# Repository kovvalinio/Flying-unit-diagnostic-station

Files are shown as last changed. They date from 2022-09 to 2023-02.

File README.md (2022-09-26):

# Flying-unit-diagnostic-station
This is the development repository for the embedded system created by me and Adam Polus as a diploma thesis.
The goal is to create the system that will collect data from sensors and pass them wirlessly to PC. 
The system will be attached to a drone and will constantly provide data from accelerometers and microphones.
Data will held the information about vibrations generated by motors.

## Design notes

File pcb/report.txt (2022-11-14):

Info: Processing symbol 'P1:Connector_Molex:Molex_PicoBlade_53047-0610_1x06_P1.25mm_Vertical'.
Info: Processing symbol 'U1:Package_QFP:LQFP-100_14x14mm_P0.5mm'.
Connected U1 pin 59 to unconnected-(U1-Pad59).
Connected U1 pin 72 to /SWDIO.
Add net unconnected-(U1-Pad60).
Connected U1 pin 60 to unconnected-(U1-Pad60).
Add net unconnected-(U1-Pad61).
Connected U1 pin 61 to unconnected-(U1-Pad61).
Add net unconnected-(U1-Pad62).
Connected U1 pin 62 to unconnected-(U1-Pad62).
Add net unconnected-(U1-Pad63).
Connected U1 pin 63 to unconnected-(U1-Pad63).
Add net unconnected-(U1-Pad64).
Connected U1 pin 64 to unconnected-(U1-Pad64).
Add net unconnected-(U1-Pad65).
Connected U1 pin 65 to unconnected-(U1-Pad65).
Add net unconnected-(U1-Pad66).
Connected U1 pin 66 to unconnected-(U1-Pad66).
Add net unconnected-(U1-Pad67).
Connected U1 pin 67 to unconnected-(U1-Pad67).
Add net unconnected-(U1-Pad68).
Connected U1 pin 68 to unconnected-(U1-Pad68).
Add net unconnected-(U1-Pad69).
Connected U1 pin 69 to unconnected-(U1-Pad69).
Add net unconnected-(U1-Pad70).
Connected U1 pin 70 to unconnected-(U1-Pad70).
Add net unconnected-(U1-Pad71).
Connected U1 pin 71 to unconnected-(U1-Pad71).
Add net unconnected-(U1-Pad73).
Connected U1 pin 52 to unconnected-(U1-Pad52).
Add net unconnected-(U1-Pad46).
Connected U1 pin 46 to unconnected-(U1-Pad46).
Add net unconnected-(U1-Pad47).
Connected U1 pin 47 to unconnected-(U1-Pad47).
Add net unconnected-(U1-Pad48).
Connected U1 pin 48 to unconnected-(U1-Pad48).
Add net unconnected-(U1-Pad49).
Connected U1 pin 49 to unconnected-(U1-Pad49).
Add net unconnected-(U1-Pad50).
Connected U1 pin 50 to unconnected-(U1-Pad50).
Add net unconnected-(U1-Pad51).
Connected U1 pin 51 to unconnected-(U1-Pad51).
Add net unconnected-(U1-Pad52).
Add net unconnected-(U1-Pad59).
Add net unconnected-(U1-Pad53).
Connected U1 pin 53 to unconnected-(U1-Pad53).
Add net unconnected-(U1-Pad54).
Connected U1 pin 54 to unconnected-(U1-Pad54).
Add net unconnected-(U1-Pad55).
Connected U1 pin 55 to unconnected-(U1-Pad55).
Add net unconnected-(U1-Pad56).
Connected U1 pin 56 to unconnected-(U1-Pad56).
Add net unconnected-(U1-Pad57).
Connected U1 pin 57 to unconnected-(U1-Pad57).
Add net unconnected-(U1-Pad58).
Connected U1 pin 58 to unconnected-(U1-Pad58).
Connected U1 pin 94 to unconnected-(U1-Pad94).
Connected U1 pin 87 to unconnected-(U1-Pad87).
Add net unconnected-(U1-Pad88).
Connected U1 pin 88 to unconnected-(U1-Pad88).
Connected U1 pin 89 to /SWO.
Add net unconnected-(U1-Pad90).
Connected U1 pin 90 to unconnected-(U1-Pad90).
Add net unconnected-(U1-Pad91).
Connected U1 pin 91 to unconnected-(U1-Pad91).
Add net unconnected-(U1-Pad92).
Connected U1 pin 92 to unconnected-(U1-Pad92).
Add net unconnected-(U1-Pad93).
Connected U1 pin 93 to unconnected-(U1-Pad93).
Add net unconnected-(U1-Pad94).
Add net unconnected-(U1-Pad87).
Add net unconnected-(U1-Pad95).
Connected U1 pin 95 to unconnected-(U1-Pad95).
Add net unconnected-(U1-Pad96).
Connected U1 pin 96 to unconnected-(U1-Pad96).
Add net unconnected-(U1-Pad97).
Connected U1 pin 97 to unconnected-(U1-Pad97).
Add net unconnected-(U1-Pad98).
Connected U1 pin 98 to unconnected-(U1-Pad98).
Add net unconnected-(U1-Pad99).
Connected U1 pin 99 to unconnected-(U1-Pad99).
Add net unconnected-(U1-Pad100).
Connected U1 pin 100 to unconnected-(U1-Pad100).
Connected U1 pin 80 to unconnected-(U1-Pad80).
Connected U1 pin 73 to unconnected-(U1-Pad73).
Add net unconnected-(U1-Pad74).
Connected U1 pin 74 to unconnected-(U1-Pad74).
Add net unconnected-(U1-Pad75).
Connected U1 pin 75 to unconnected-(U1-Pad75).
Connected U1 pin 76 to /SWCLK.
Add net unconnected-(U1-Pad77).
Connected U1 pin 77 to unconnected-(U1-Pad77).
Add net unconnected-(U1-Pad78).
Connected U1 pin 78 to unconnected-(U1-Pad78).
Add net unconnected-(U1-Pad79).
Connected U1 pin 79 to unconnected-(U1-Pad79).
Add net unconnected-(U1-Pad80).
Add net unconnected-(U1-Pad45).
Add net unconnected-(U1-Pad81).
Connected U1 pin 81 to unconnected-(U1-Pad81).
Add net unconnected-(U1-Pad82).
Connected U1 pin 82 to unconnected-(U1-Pad82).
Add net unconnected-(U1-Pad83).
Connected U1 pin 83 to unconnected-(U1-Pad83).
Add net unconnected-(U1-Pad84).
Connected U1 pin 84 to unconnected-(U1-Pad84).
Add net unconnected-(U1-Pad85).
Connected U1 pin 85 to unconnected-(U1-Pad85).
Add net unconnected-(U1-Pad86).
Connected U1 pin 86 to unconnected-(U1-Pad86).
Connected U1 pin 10 to GND.
Connected U1 pin 3 to unconnected-(U1-Pad3).
Add net unconnected-(U1-Pad4).
Connected U1 pin 4 to unconnected-(U1-Pad4).
Add net unconnected-(U1-Pad5).
Connected U1 pin 5 to unconnected-(U1-Pad5).
Add net unconnected-(U1-Pad6).
Connected U1 pin 6 to unconnected-(U1-Pad6).
Add net unconnected-(U1-Pad7).
Connected U1 pin 7 to unconnected-(U1-Pad7).
Add net unconnected-(U1-Pad8).
Connected U1 pin 8 to unconnected-(U1-Pad8).
Add net unconnected-(U1-Pad9).
Connected U1 pin 9 to unconnected-(U1-Pad9).
Add net unconnected-(U1-Pad3).
Connected U1 pin 11 to VDD.
Add net unconnected-(U1-Pad12).
Connected U1 pin 12 to unconnected-(U1-Pad12).
Add net unconnected-(U1-Pad13).
Connected U1 pin 13 to unconnected-(U1-Pad13).
Connected U1 pin 14 to /NRST.
Add net unconnected-(U1-Pad15).
Connected U1 pin 15 to unconnected-(U1-Pad15).
Add net unconnected-(U1-Pad16).
Connected U1 pin 16 to unconnected-(U1-Pad16).
Add net unconnected-(U1-Pad17).
Connected U1 pin 17 to unconnected-(U1-Pad17).
Add net GND.
Added P1 (footprint 'Connector_Molex:Molex_PicoBlade_53047-0610_1x06_P1.25mm_Vertical').
Changed REF** reference designator to P1.
Changed P1 value from Molex_PicoBlade_53047-0610_1x06_P1.25mm_Vertical to Conn_01x06.
Updated P1 symbol association from  to /8a48b6fa-d742-44c7-b137-f06bed0efe74.
Updated P1 properties.
Add net /NRST.
Connected P1 pin 1 to /NRST.
Add net /SWO.
Connected P1 pin 2 to /SWO.
Add net /SWDIO.
Connected P1 pin 3 to /SWDIO.
Add net /SWCLK.
Connected P1 pin 4 to /SWCLK.
Add net unconnected-(U1-Pad18).
Connected P1 pin 5 to GND.
Add net VDD.
Connected P1 pin 6 to VDD.
Added U1 (footprint 'Package_QFP:LQFP-100_14x14mm_P0.5mm').
Changed REF** reference designator to U1.
Changed U1 value from LQFP-100_14x14mm_P0.5mm to STM32F756VGTx.
Updated U1 symbol association from  to /31b49864-d5c3-4310-8056-1381014dc615.
Updated U1 properties.
Add net unconnected-(U1-Pad1).
Connected U1 pin 1 to unconnected-(U1-Pad1).
Add net unconnected-(U1-Pad2).
Connected U1 pin 2 to unconnected-(U1-Pad2).
Connected U1 pin 38 to unconnected-(U1-Pad38).
Add net unconnected-(U1-Pad32).
Connected U1 pin 32 to unconnected-(U1-Pad32).
Add net unconnected-(U1-Pad33).
Connected U1 pin 33 to unconnected-(U1-Pad33).
Add net unconnected-(U1-Pad34).
Connected U1 pin 34 to unconnected-(U1-Pad34).
Add net unconnected-(U1-Pad35).
Connected U1 pin 35 to unconnected-(U1-Pad35).
Add net unconnected-(U1-Pad36).
Connected U1 pin 36 to unconnected-(U1-Pad36).
Add net unconnected-(U1-Pad37).
Connected U1 pin 37 to unconnected-(U1-Pad37).
Add net unconnected-(U1-Pad38).
Connected U1 pin 31 to unconnected-(U1-Pad31).
Add net unconnected-(U1-Pad39).
Connected U1 pin 39 to unconnected-(U1-Pad39).
Add net unconnected-(U1-Pad40).
Connected U1 pin 40 to unconnected-(U1-Pad40).
Add net unconnected-(U1-Pad41).
Connected U1 pin 41 to unconnected-(U1-Pad41).
Add net unconnected-(U1-Pad42).
Connected U1 pin 42 to unconnected-(U1-Pad42).
Add net unconnected-(U1-Pad43).
Connected U1 pin 43 to unconnected-(U1-Pad43).
Add net unconnected-(U1-Pad44).
Connected U1 pin 44 to unconnected-(U1-Pad44).
Add net unconnected-(U1-Pad25).
Connected U1 pin 18 to unconnected-(U1-Pad18).
Add net unconnected-(U1-Pad19).
Connected U1 pin 19 to unconnected-(U1-Pad19).
Add net unconnected-(U1-Pad20).
Connected U1 pin 20 to unconnected-(U1-Pad20).
Add net unconnected-(U1-Pad21).
Connected U1 pin 21 to unconnected-(U1-Pad21).
Add net unconnected-(U1-Pad22).
Connected U1 pin 22 to unconnected-(U1-Pad22).
Add net unconnected-(U1-Pad23).
Connected U1 pin 23 to unconnected-(U1-Pad23).
Add net unconnected-(U1-Pad24).
Connected U1 pin 24 to unconnected-(U1-Pad24).
Connected U1 pin 45 to unconnected-(U1-Pad45).
Connected U1 pin 25 to unconnected-(U1-Pad25).
Add net unconnected-(U1-Pad26).
Connected U1 pin 26 to unconnected-(U1-Pad26).
Add net unconnected-(U1-Pad27).
Connected U1 pin 27 to unconnected-(U1-Pad27).
Add net unconnected-(U1-Pad28).
Connected U1 pin 28 to unconnected-(U1-Pad28).
Add net unconnected-(U1-Pad29).
Connected U1 pin 29 to unconnected-(U1-Pad29).
Add net unconnected-(U1-Pad30).
Connected U1 pin 30 to unconnected-(U1-Pad30).
Add net unconnected-(U1-Pad31).

Info: Total warnings: 0, errors: 0.

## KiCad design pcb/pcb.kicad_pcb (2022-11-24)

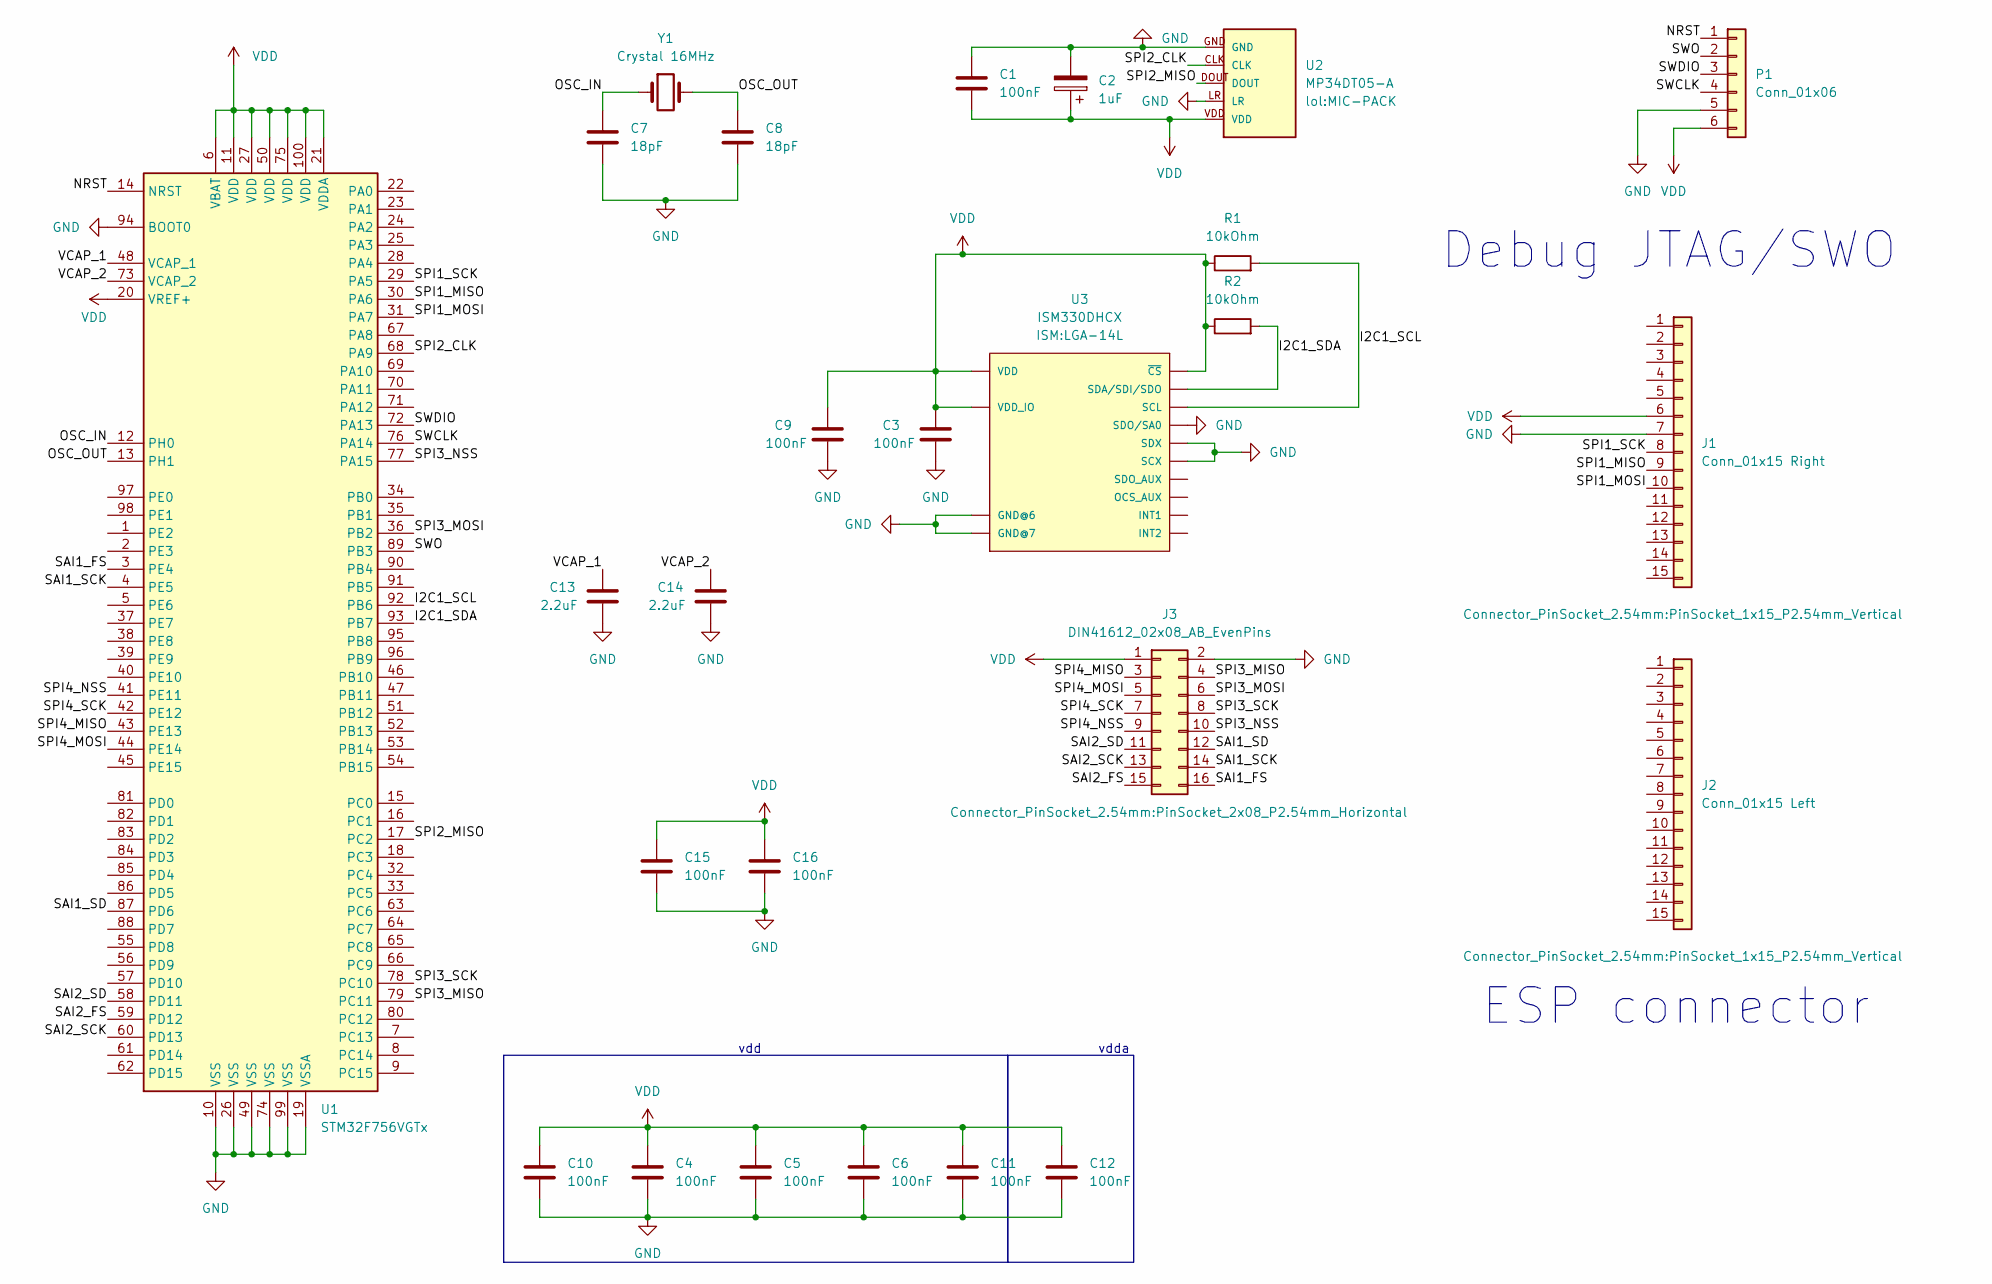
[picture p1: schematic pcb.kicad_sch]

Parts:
C1, C4, C5, C6, C10, C11, C12, C15, C16: 100nF; C_0603_1608Metric
C2: 1uF; C_0603_1608Metric
C3, C9: 100nF; R_0603_1608Metric
C7, C8: 18pF; C_0603_1608Metric
C13, C14: 2.2uF; R_0603_1608Metric
J1: Conn_01x15 Right; PinSocket_1x15_P2.54mm_Vertical
J2: Conn_01x15 Left; PinSocket_1x15_P2.54mm_Vertical
J3: DIN41612_02x08_AB_EvenPins; PinSocket_2x08_P2.54mm_Horizontal
P1: Conn_01x06; Molex_PicoBlade_53047-0610_1x06_P1.25mm_Vertical
R1, R2: 10kOhm; R_0603_1608Metric
U1: STM32F756VGTx; LQFP-100_14x14mm_P0.5mm
U2: MP34DT05-A; MIC-PACK
U3: ISM330DHCX; LGA-14L
Y1: Crystal 16MHz; Crystal_SMD_Abracon_ABM3-2Pin_5.0x3.2mm

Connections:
/I2C1_SCL: R1.2, U1.92 (PB6), U3.P13 (SCL)
/I2C1_SDA: R2.2, U1.93 (PB7), U3.P14 (SDA/SDI/SDO)
/NRST: P1.1, U1.14 (NRST)
/OSC_IN: C7.2, U1.12 (PH0), Y1.1
/OSC_OUT: C8.2, U1.13 (PH1), Y1.2
/SAI1_FS: J3.16 (Pin_b16), U1.3 (PE4)
/SAI1_SCK: J3.14 (Pin_b14), U1.4 (PE5)
/SAI1_SD: J3.12 (Pin_b12), U1.87 (PD6)
/SAI2_FS: J3.15 (Pin_a16), U1.59 (PD12)
/SAI2_SCK: J3.13 (Pin_a14), U1.60 (PD13)
/SAI2_SD: J3.11 (Pin_a12), U1.58 (PD11)
/SPI1_MISO: J1.9, U1.30 (PA6)
/SPI1_MOSI: J1.10, U1.31 (PA7)
/SPI1_SCK: J1.8, U1.29 (PA5)
/SPI2_CLK: U1.68 (PA9), U2.CLK
/SPI2_MISO: U1.17 (PC2), U2.DOUT
/SPI3_MISO: J3.4 (Pin_b4), U1.79 (PC11)
/SPI3_MOSI: J3.6 (Pin_b6), U1.36 (PB2)
/SPI3_NSS: J3.10 (Pin_b10), U1.77 (PA15)
/SPI3_SCK: J3.8 (Pin_b8), U1.78 (PC10)
/SPI4_MISO: J3.3 (Pin_a4), U1.43 (PE13)
/SPI4_MOSI: J3.5 (Pin_a6), U1.44 (PE14)
/SPI4_NSS: J3.9 (Pin_a10), U1.41 (PE11)
/SPI4_SCK: J3.7 (Pin_a8), U1.42 (PE12)
/SWCLK: P1.4, U1.76 (PA14)
/SWDIO: P1.3, U1.72 (PA13)
/SWO: P1.2, U1.89 (PB3)
/VCAP_1: C13.1, U1.48 (VCAP_1)
/VCAP_2: C14.1, U1.73 (VCAP_2)
GND: C1.2, C2.2, C3.2, C4.1, C5.1, C6.1, C7.1, C8.1, C9.2, C10.1, C11.1, C12.1, C13.2, C14.2, C15.1, C16.1, J1.7, J3.2 (Pin_b2), P1.5, U1.10 (VSS), U1.19 (VSSA), U1.26 (VSS), U1.49 (VSS), U1.74 (VSS), U1.94 (BOOT0), U1.99 (VSS), U2.GND, U2.LR, U3.P1 (SDO/SA0), U3.P2 (SDX), U3.P3 (SCX), U3.P6 (GND@6), U3.P7 (GND@7)
VDD: C1.1, C2.1, C3.1, C4.2, C5.2, C6.2, C9.1, C10.2, C11.2, C12.2, C15.2, C16.2, J1.6, J3.1 (Pin_a2), P1.6, R1.1, R2.1, U1.6 (VBAT), U1.11 (VDD), U1.20 (VREF+), U1.21 (VDDA), U1.27 (VDD), U1.50 (VDD), U1.75 (VDD), U1.100 (VDD), U2.VDD, U3.P5 (VDD_IO), U3.P8 (VDD), U3.P12 (~CS)

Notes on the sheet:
ESP connector
vdd
Debug JTAG/SWO
vdda

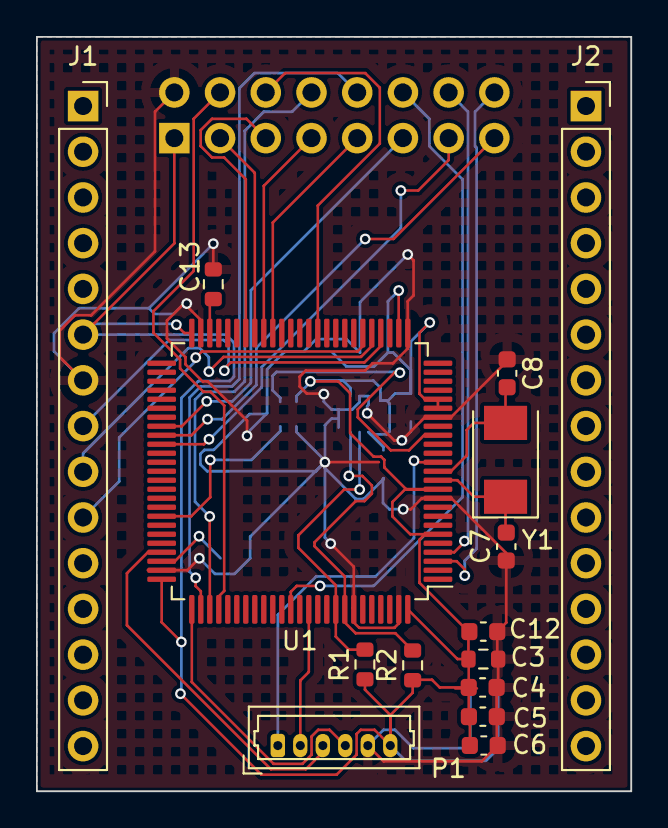
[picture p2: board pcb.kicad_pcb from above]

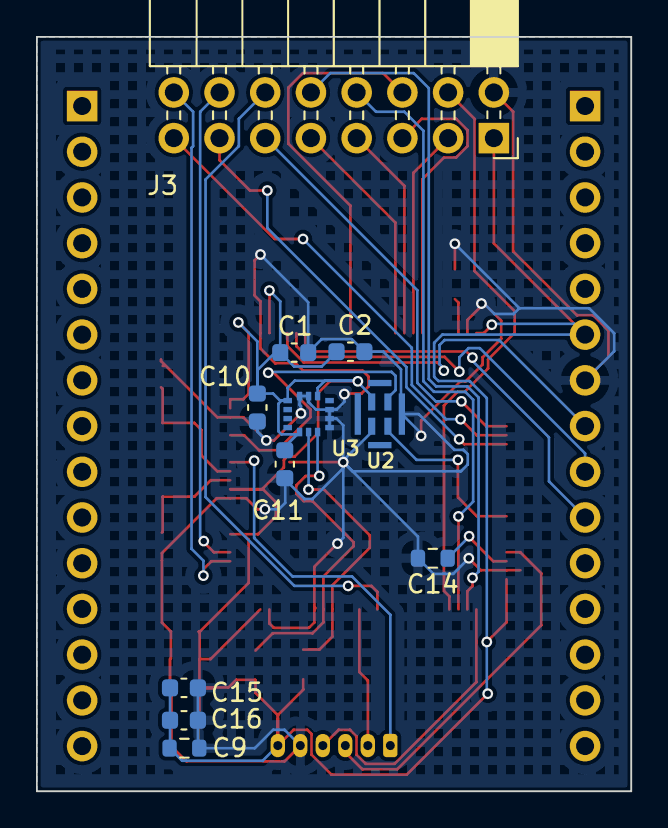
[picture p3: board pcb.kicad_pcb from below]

Board: 2 copper layers, 33.0 x 41.9 mm, 26 parts (11 on the bottom side), 31 nets.

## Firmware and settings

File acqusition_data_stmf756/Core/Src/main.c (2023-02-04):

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
/* Includes ------------------------------------------------------------------*/
#include "main.h"

#include "crc.h"

#include "dma.h"

#include "i2c.h"

#include "pdm2pcm.h"

#include "spi.h"

#include "tim.h"

#include "usart.h"

#include "gpio.h"

#include "app_mems.h"

/* USER CODE BEGIN Includes */
#include <accelerometer_config.h>

/* USER CODE END Includes */

/* USER CODE BEGIN PD */
#define PDM_BUF 192
#define PCM_MID_BUF 24
#define PCM_BIG_BUF 48000
#define mic_buffer_bytes 96080

#define ACC_BUFFER_SIZE 2400
#define acc_buffer_bytes 14412

/* USER CODE END PD */


/* USER CODE BEGIN PV */

uint8_t PDMbuff[PDM_BUF];
uint16_t pcmSmallBuffer[PCM_MID_BUF];
uint16_t pcmBigBuffer[PCM_BIG_BUF];
uint8_t micRxFlag = 0;
uint32_t fifoIterator = 0;
uint8_t mic_data_to_send[mic_buffer_bytes];

uint8_t espTxFlag = 0;

acceleration acc_vector[ACC_BUFFER_SIZE];
uint32_t acc_iterator = 0;
ism330dhcx_axis3bit16_t data_raw;
uint8_t acc_data_to_send[acc_buffer_bytes];
uint8_t acc_aqcuisition_flag = 0;

/* USER CODE END PV */

void SystemClock_Config(void);
/* USER CODE BEGIN PFP */

//Function storing  sound data in a big buffer
//Whenever the big buffer is full espTxFlag is set
//to start transmiting
void FifoWrite_B(uint16_t data) {

  if (fifoIterator != PCM_BIG_BUF) {

    pcmBigBuffer[fifoIterator] = data;

    fifoIterator++;

  }
  if (fifoIterator == PCM_BIG_BUF) {

    espTxFlag = 1;

  }

}

//Callbacks allowing pipelining in the i2s interface.
//Its used to ensure constant data flow.
void HAL_SPI_RxHalfCpltCallback(SPI_HandleTypeDef * hspi) {

  if (hspi -> Instance == SPI2) {

    micRxFlag = 1;

  }

}

void HAL_SPI_RxCpltCallback(SPI_HandleTypeDef * hspi) {

  if (hspi -> Instance == SPI2) {

    micRxFlag = 2;

  }

}

void HAL_TIM_PeriodElapsedCallback(TIM_HandleTypeDef * htim) {

  if (htim -> Instance == TIM1) {

    if (acc_aqcuisition_flag == 0) {

      measure_and_add( & data_raw.i16bit);

    }

  }

}
void HAL_I2C_MemRxCpltCallback(I2C_HandleTypeDef * hi2c) {

  if (hi2c -> Instance == I2C4) {

    acc_vector[acc_iterator].x = (int16_t)((float)((float)(data_raw.i16bit[0]) * ACC_SENS));
    acc_vector[acc_iterator].y = (int16_t)((float)((float)(data_raw.i16bit[1]) * ACC_SENS));
    acc_vector[acc_iterator].z = (int16_t)((float)((float)(data_raw.i16bit[2]) * ACC_SENS));

    acc_iterator++;

    if (acc_iterator == ACC_BUFFER_SIZE) {

      acc_aqcuisition_flag = 1;

    }

  }

}

void prepare_mic_data_to_send()
{

  uint8_t pack_nr = 0;

  uint16_t * ptr = & pcmBigBuffer[0];

  for (int i = 0; i < mic_buffer_bytes; i = i + 2) {

    if (i % 1201 == 0) {

      mic_data_to_send[i] = pack_nr;

      pack_nr++;

      i++;

    }

    else if (i % 1201 != 0) {

      mic_data_to_send[i] = ( * ptr >> 8);

      mic_data_to_send[i + 1] = ( * ptr & 0xFF);

      if (i < mic_buffer_bytes - 1) {

        ptr++;

      }

    }

  }

}

void prepare_acc_data_to_send()
{
  uint8_t pack_nr = 128;

  acceleration * ptr = & acc_vector[0];

  for (int i = 0; i < acc_buffer_bytes; i = i + 6)
  {

    if (i % 1201 == 0) {

      acc_data_to_send[i] = pack_nr;

      pack_nr++;

      i++;

    }
    else if (i % 1201 != 0){

      acc_data_to_send[i] = (ptr -> x >> 8);

      acc_data_to_send[i + 1] = (ptr -> x & 0xFF);

      acc_data_to_send[i + 2] = (ptr -> y >> 8);

      acc_data_to_send[i + 3] = (ptr -> y & 0xFF);

      acc_data_to_send[i + 4] = (ptr -> z >> 8);

      acc_data_to_send[i + 5] = (ptr -> z & 0xFF);

      if (i < acc_buffer_bytes - 1) {

    	  ptr++;
      }

    }

  }

}

/* USER CODE END PFP */

/**
 * @brief  The application entry point.
 * @retval int
 */
int main(void) {
  /* MCU Configuration--------------------------------------------------------*/

  /* Reset of all peripherals, Initializes the Flash interface and the Systick. */
  HAL_Init();

  /* Configure the system clock */
  SystemClock_Config();

  /* Initialize all configured peripherals */
  MX_GPIO_Init();
  MX_CRC_Init();
  MX_DMA_Init();
  MX_PDM2PCM_Init();
  MX_SPI2_Init();
  MX_UART4_Init();
  MX_I2C1_Init();
  MX_TIM1_Init();
  MX_MEMS_Init();
  /* USER CODE BEGIN 2 */
  HAL_SPI_Receive_DMA( & hspi2, PDMbuff, PDM_BUF);
  HAL_TIM_Base_Start_IT( & htim1);
  /* USER CODE END 2 */

  /* Infinite loop */
  /* USER CODE BEGIN WHILE */
  while (1) {

    //Read values mode
    if (espTxFlag == 0 && fifoIterator != PCM_BIG_BUF) {

      if (micRxFlag == 1) {

        if (PDM_Filter( & PDMbuff[0], & pcmSmallBuffer[0], & PDM1_filter_handler) != 0) {

          Error_Handler();

        }

        for (int i = 0; i < PCM_MID_BUF; i++) {

          FifoWrite_B(pcmSmallBuffer[i]);

        }

        micRxFlag = 0;

      }

      if (micRxFlag == 2) {

        if (PDM_Filter( & PDMbuff[PDM_BUF / 2], & pcmSmallBuffer[0], & PDM1_filter_handler) != 0) {

          Error_Handler();

        }

        for (int i = 0; i < PCM_MID_BUF; i++) {

          FifoWrite_B(pcmSmallBuffer[i]);

        }

        micRxFlag = 0;
      }
    }

    //Transmit mode
    if (espTxFlag == 1 && acc_aqcuisition_flag == 1) {

      prepare_mic_data_to_send();
      prepare_acc_data_to_send();

      for (int i = 0; i < 80; i++) {

        HAL_UART_Transmit( & huart4, & mic_data_to_send[1201 * i], 1201, HAL_MAX_DELAY);
        HAL_Delay(1);

      }

      for (int i = 0; i < 12; i++) {

        HAL_UART_Transmit( & huart4, & acc_data_to_send[1201 * i], 1201, HAL_MAX_DELAY);
        HAL_Delay(1);

      }

      espTxFlag = 0;
      fifoIterator = 0;
      acc_aqcuisition_flag = 0;
      acc_iterator = 0;

    }
    /* USER CODE END WHILE */

    /* USER CODE BEGIN 3 */
  }
  /* USER CODE END 3 */
}

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


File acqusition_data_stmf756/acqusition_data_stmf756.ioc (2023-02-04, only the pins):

Mcu.UserName=STM32F756VGTx
PA1.Signal=UART4_RX
PA6.Signal=GPXTI6
PA7.Signal=GPIO_Input
PA9.Signal=SPI2_SCK
PB3.Signal=GPIO_Output
PB6.Signal=I2C1_SCL
PB7.Signal=I2C1_SDA
PC10.Signal=UART4_TX
PC2.Signal=SPI2_MISO
PD12.Signal=I2C4_SCL
PD13.Signal=I2C4_SDA
PD5.Signal=GPXTI5
PE0.Signal=UART8_RX
PE1.Signal=UART8_TX

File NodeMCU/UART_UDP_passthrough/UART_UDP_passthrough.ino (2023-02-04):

#include <ESP8266WiFi.h>
#include <WiFiClient.h>
#include <WiFiUdp.h>
#define size_pack 1201

uint8_t c;
uint8_t array_paczka[size_pack];
int u=0;
const char* ssid = "esp";
unsigned int localPort = 7777;
WiFiUDP udp;

void setup() {
    Serial.begin(115200);
    WiFi.softAP(ssid);
  udp.begin(localPort);
}

void loop() {
int rxlen = Serial.available(); // number of bytes available in Serial buffer
 if (Serial.available()>0){
    rxlen = Serial.readBytes(array_paczka, size_pack);
    Serial.print(array_paczka[0]);
    udp.beginPacket("192.168.4.2", 15200);
    udp.write(array_paczka, size_pack);
    udp.endPacket();
 }
}

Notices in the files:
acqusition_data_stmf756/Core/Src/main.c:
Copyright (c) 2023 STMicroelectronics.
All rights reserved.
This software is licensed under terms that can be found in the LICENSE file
